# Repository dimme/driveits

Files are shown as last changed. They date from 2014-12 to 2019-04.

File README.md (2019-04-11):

# Drive ITS

This is the source code and schematics for the system described in the following papers:

* D. Vlastaras, T. Abbas, D. Leston, F. Tufvesson:
Vehicle Detection through Wireless Vehicular Communication, EURASIP Journal on Wireless Communications and Networking, 2014 2014:146.
* D. Vlastaras, T. Abbas, D. Leston, F. Tufvesson:
Universal Medium Range Radar and IEEE 802.11p Modem Solution for Integrated Traffic Safety, 13th International Conference on ITS Telecommunications, Tampere, Finland, pp. 193-197, 2013-11-05.
* D. Vlastaras, D. Leston:
Improved Traffic Safety by Wireless Vehicular Communication, Lund University, Sweden, 2013-06-17.

Everything is released under the GPLv3 license. For any commercial purposes please contact dimitrios@NOSPAM@cryodev.se

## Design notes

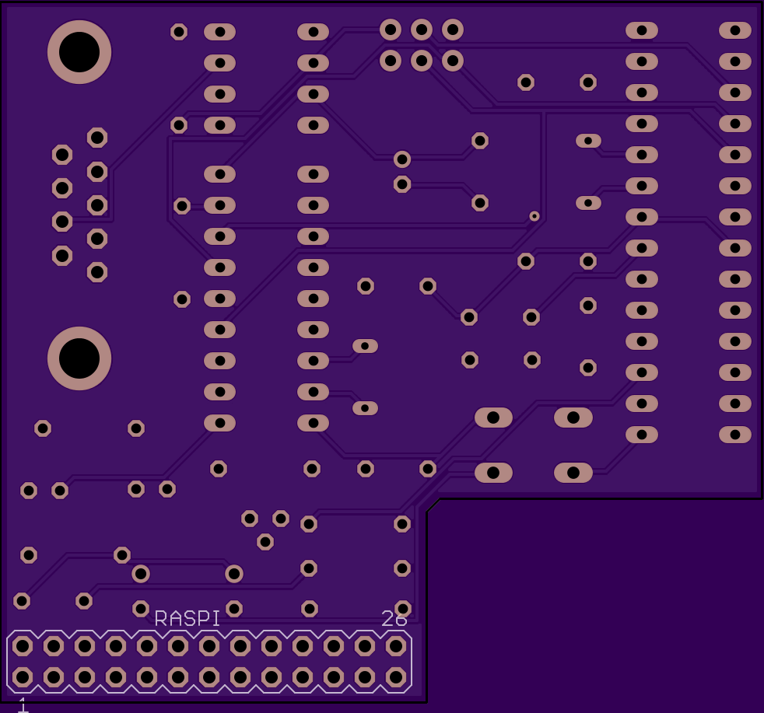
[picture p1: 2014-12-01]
hardware/pictures/bottom oshpark.png

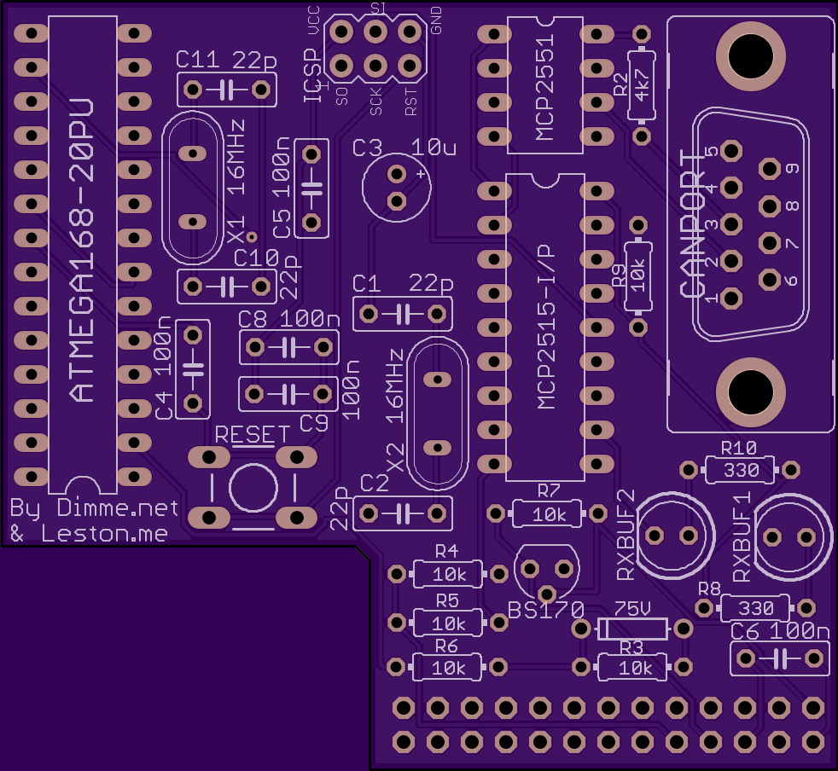
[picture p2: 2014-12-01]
hardware/pictures/top oshpark.png

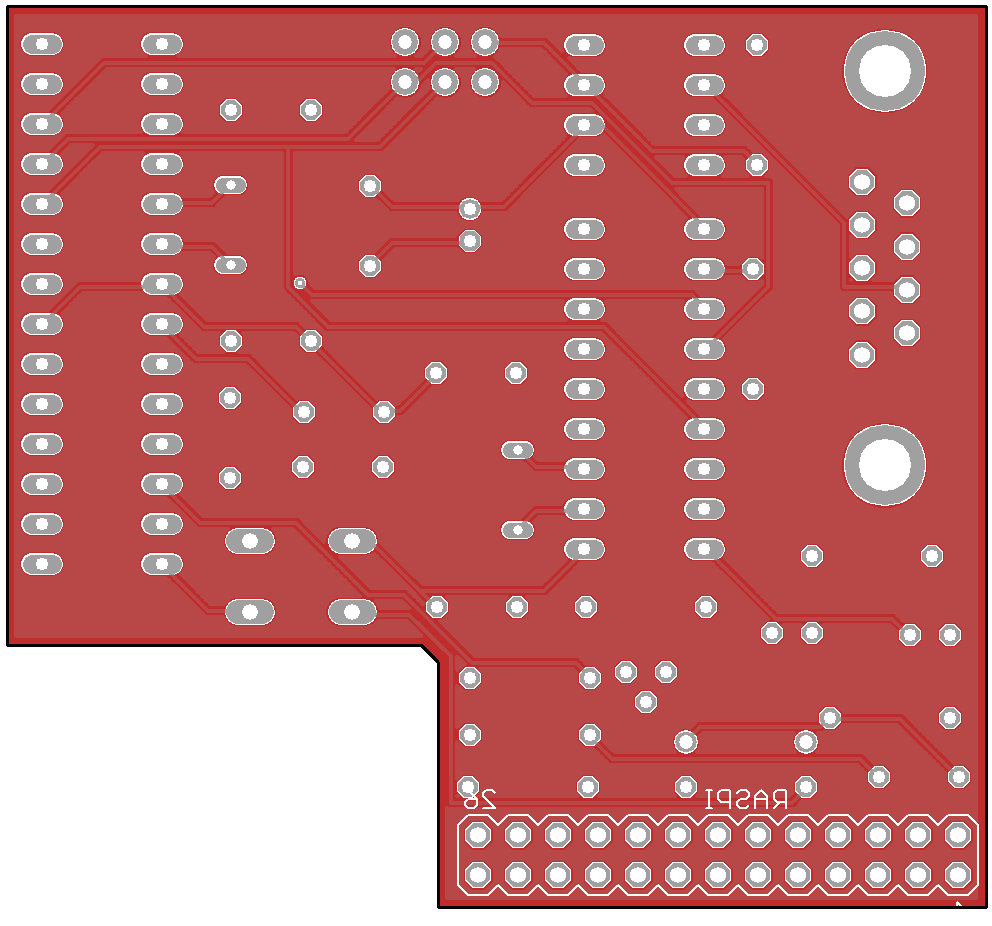
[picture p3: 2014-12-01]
hardware/pictures/bottom dirtypcbs.png

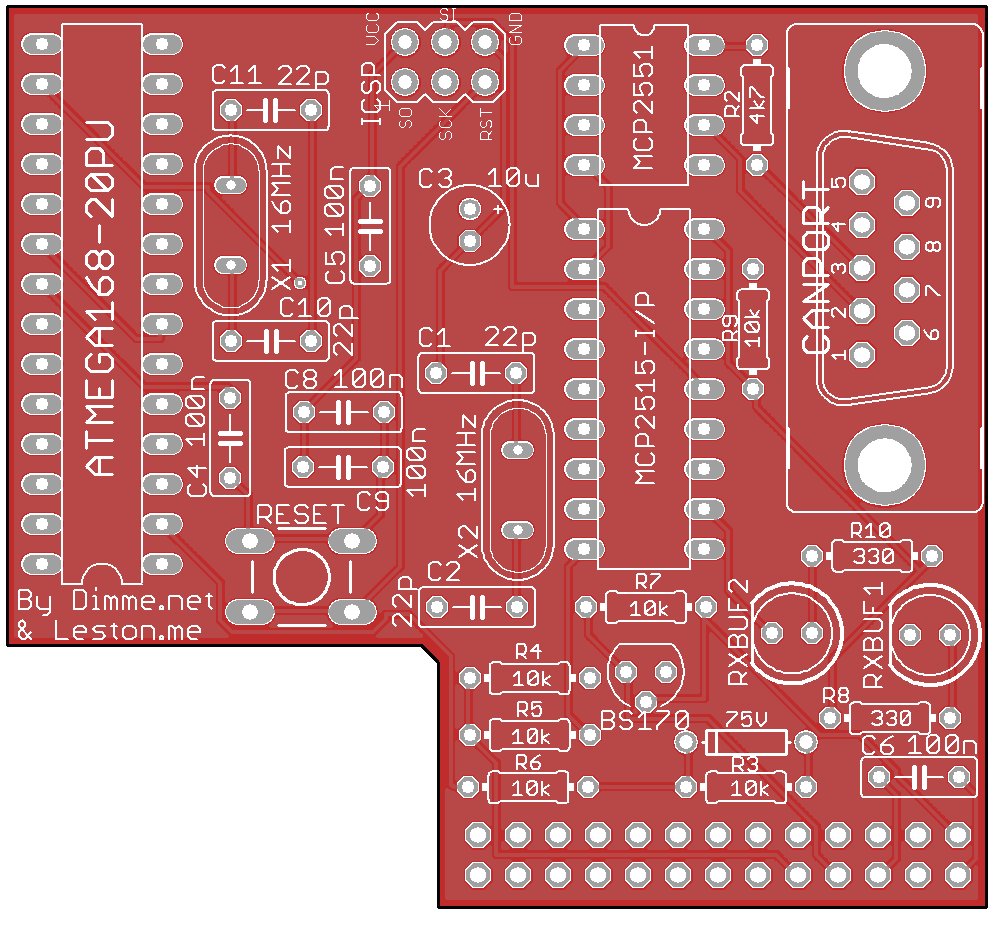
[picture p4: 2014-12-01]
hardware/pictures/top dirtypcbs.png

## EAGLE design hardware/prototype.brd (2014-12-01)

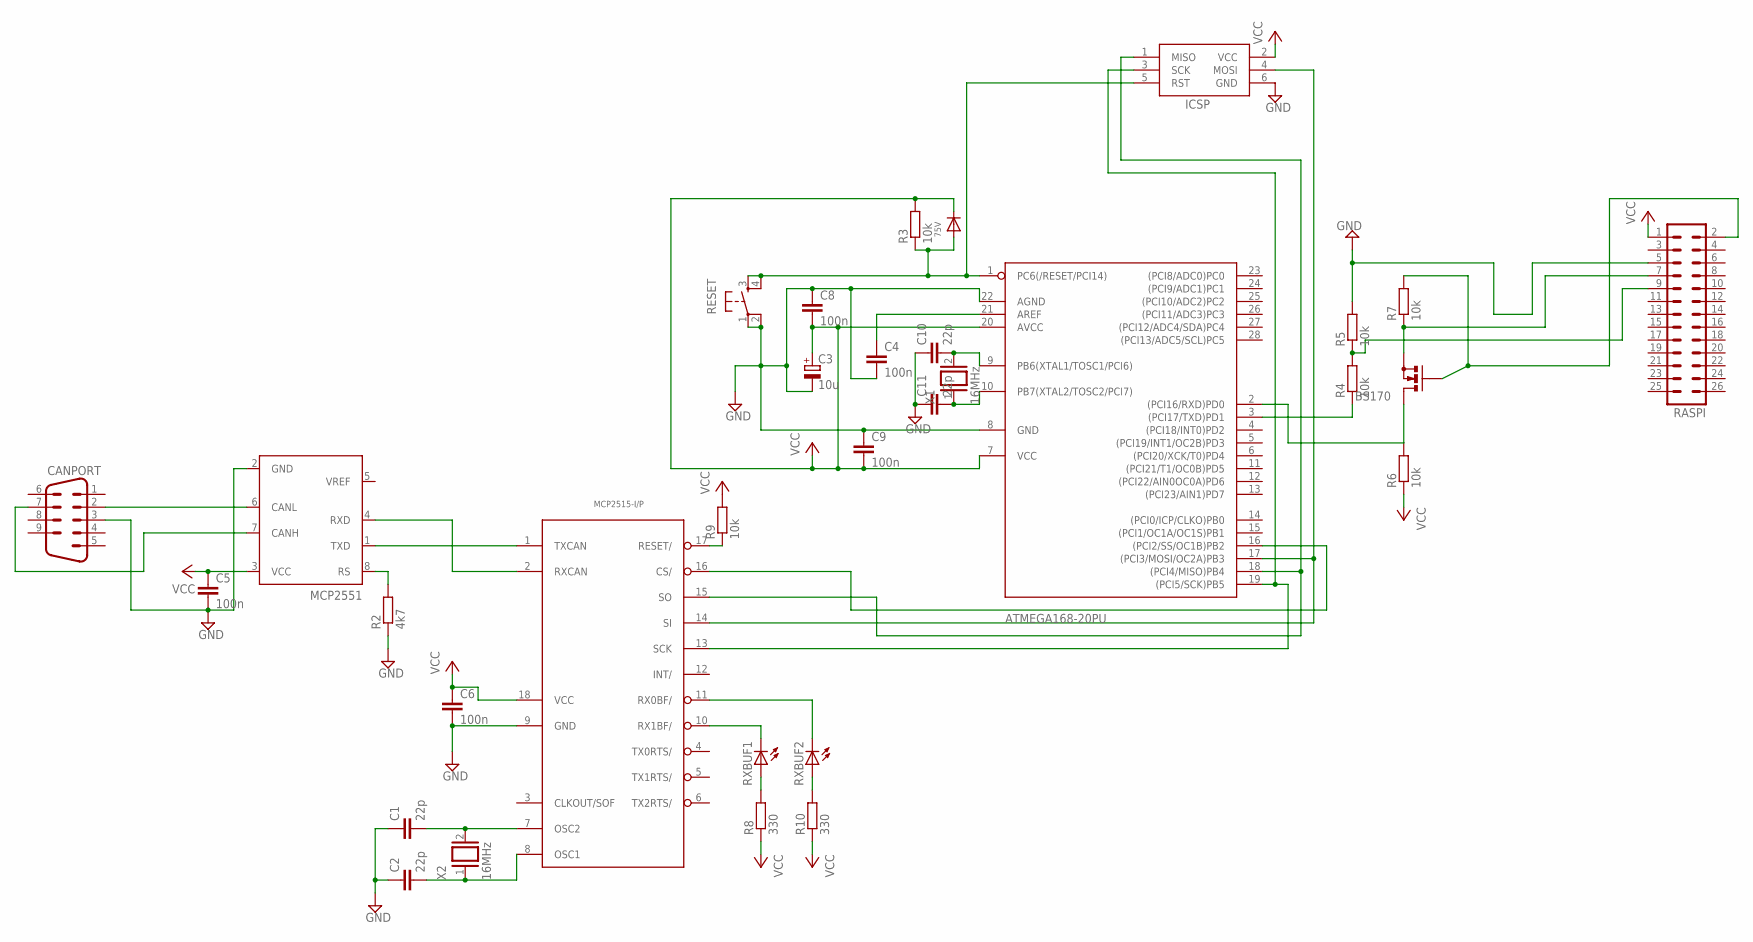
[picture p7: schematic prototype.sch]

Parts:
75V: DIODEDO-1N4148; DO-1N4148
ATMEGA168-20PU: ATMEGA168V-10P; DIL28-3
BS170: BS170; SOT54E
C1, C2, C10, C11: 22p; C050-025X075
C3: 10u; E2-5
C4, C5, C6, C8, C9: 100n; C050-025X075
CANPORT: M09VP
ICSP: AVRISP-6; AVRISP
MCP2515-I/P: MCP2515DIL; DIL18
MCP2551: PCA82C250; DIL08
R2: 4k7; 0204/7
R3, R4, R5, R6, R7, R9: 10k; 0204/7
R8, R10: 330; 0204/7
RASPI: MA13-2
RESET: DTS-6
RXBUF1, RXBUF2: LED5MM
X1, X2: 16MHz; QS

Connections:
GND: ATMEGA168-20PU.8 (GND), ATMEGA168-20PU.22 (AGND), C1.1, C2.1, C3.-, C4.2, C5.2, C6.2, C8.1, C9.1, C10.1, C11.1, CANPORT.3, ICSP.6 (GND), MCP2515-I/P.9 (GND), MCP2551.2 (GND), R2.1, R5.2, RASPI.5, RESET.1, RESET.2
unnamed: MCP2515-I/P.1 (TXCAN), MCP2551.1 (TXD)
unnamed: MCP2515-I/P.2 (RXCAN), MCP2551.4 (RXD)
unnamed: C1.2, MCP2515-I/P.7 (OSC2), X2.2
unnamed: C2.2, MCP2515-I/P.8 (OSC1), X2.1
unnamed: MCP2515-I/P.17 (RESET/), R9.1
unnamed: R8.2, RXBUF1.A
unnamed: R10.2, RXBUF2.A
unnamed: MCP2515-I/P.11 (RX0BF/), RXBUF2.K (C)
unnamed: MCP2515-I/P.10 (RX1BF/), RXBUF1.K (C)
unnamed: ATMEGA168-20PU.16 ((PCI2/SS/OC1B)PB2), MCP2515-I/P.16 (CS/)
unnamed: ATMEGA168-20PU.3 ((PCI17/TXD)PD1), R4.1
unnamed: ATMEGA168-20PU.19 ((PCI5/SCK)PB5), ICSP.3 (SCK), MCP2515-I/P.13 (SCK)
unnamed: ATMEGA168-20PU.9 (PB6(XTAL1/TOSC1/PCI6)), C10.2, X1.2
unnamed: ATMEGA168-20PU.10 (PB7(XTAL2/TOSC2/PCI7)), C11.2, X1.1
unnamed: MCP2551.8 (RS), R2.2
unnamed: ATMEGA168-20PU.21 (AREF), C4.1
unnamed: R4.2, R5.1, RASPI.9
unnamed: ATMEGA168-20PU.2 ((PCI16/RXD)PD0), BS170.D, R6.2
unnamed: 75V.A, ATMEGA168-20PU.1 (PC6(/RESET/PCI14)), ICSP.5 (RST), R3.1, RESET.3, RESET.4
unnamed: BS170.G, R7.2, RASPI.2
unnamed: ATMEGA168-20PU.18 ((PCI4/MISO)PB4), ICSP.1 (MISO), MCP2515-I/P.15 (SO)
unnamed: ATMEGA168-20PU.17 ((PCI3/MOSI/OC2A)PB3), ICSP.4 (MOSI), MCP2515-I/P.14 (SI)
unnamed: CANPORT.2, MCP2551.6 (CANL)
unnamed: CANPORT.7, MCP2551.7 (CANH)
unnamed: BS170.S, R7.1, RASPI.7
VCC: 75V.C, ATMEGA168-20PU.7 (VCC), ATMEGA168-20PU.20 (AVCC), C3.+, C5.1, C6.1, C8.2, C9.2, ICSP.2 (VCC), MCP2515-I/P.18 (VCC), MCP2551.3 (VCC), R3.2, R6.1, R8.1, R9.2, R10.1, RASPI.1

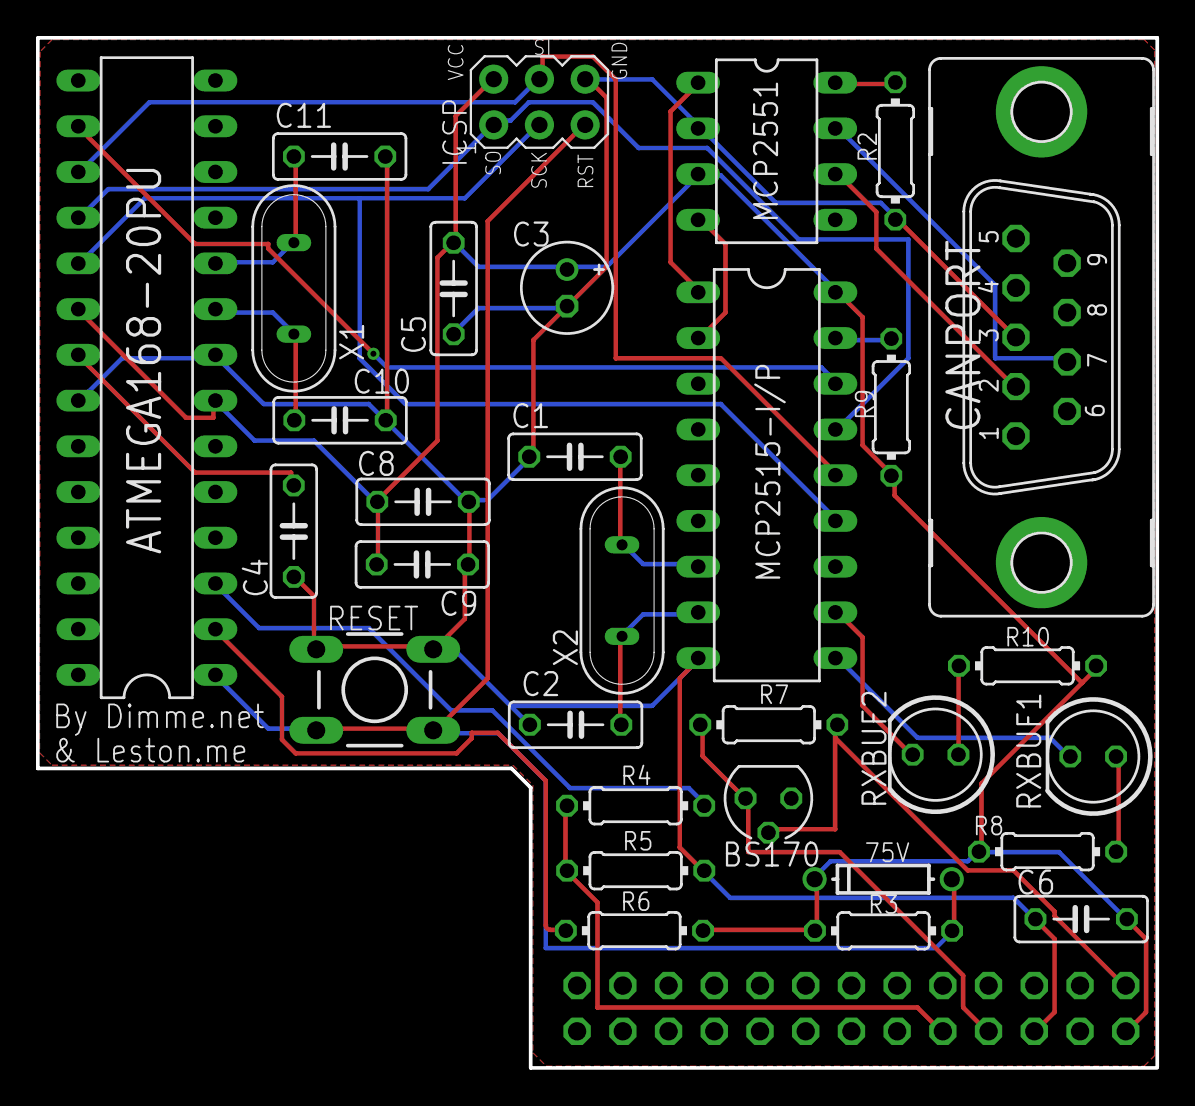
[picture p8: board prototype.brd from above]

Board: 2 copper layers, 62.2 x 57.2 mm, 32 parts (1 on the bottom side), 27 nets.

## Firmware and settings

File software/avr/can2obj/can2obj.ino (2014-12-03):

#include <SoftwareSerial.h>
#include <SPI.h>
#include "CAN.h"

// Read the report for the reason why we selected this baudrate
#define RS232_BAUD 57600

// Other defines
#define FRAME_LENGTH_WITHOUT_CRC 21

// Global variables
bool wakeUpCall = 1, sendRequest = 1, simulated = 0, valsReceived = 0;
byte rxStatus, length, frameData[8], extended, filter, startingFlag[] = { 
  0xFF,0xFF,0xFF,0xFF }, installationHeight = 5;
uint32_t frameID, oldTime = 0;

// Initiate everything
void setup() {
  // Use the defined serial port speed
  Serial.begin(RS232_BAUD);

  // Initialize CAN bus class
  // This class initializes SPI communications with MCP2515
  CAN.begin();
  delay(10);
  CAN.baudConfig();
  delay(10);

  CAN.resetFiltersAndMasks();
  CAN.toggleRxBuffer0Acceptance(true, false);
  CAN.toggleRxBuffer1Acceptance(true, false);
  CAN.setMode(NORMAL); // We send ACK's to every message that it is received.
}

// Send command for normal or simulated objects
void requestObjects(){
  byte data[] = { 0xFF,0x00,0x00,0x00,0x00,0x00,0x00,0x00 };
  if (simulated) data[4] = 0x08;
  sendCommand(data);
}

// Send the command that set the installation height in meters
// Accepted values: 1...10 meters
void setInstallationHeight() {
  byte data[] = { 0xFF,0x01,0x00,0xAC,installationHeight,0x00,0x00,0x00 };
  sendCommand(data);
}

// Function for send a command to the radar
void sendCommand(byte data[]) {
  uint32_t frame_id = 0x3F2;
  byte length = 8;
  CAN.load_ff_0(length, &frame_id, data, false);
}

// Checks if a second has passed
//void checkIfSecondPassed() {
//  uint32_t time = millis();
//  if (time > oldTime + 1000) {
//    framesSentThisSecond = 0;
//    oldTime = time;
//  }
//}

// Checksum calculation for the frame
char checksum(const char * str) {
  uint8_t sum = 0;
  for (uint8_t i = 0; i < FRAME_LENGTH_WITHOUT_CRC; i++) {
    sum += (uint8_t)str[i];
  }
  return 'H' + sum % 16;
}

// Runtime loop
void loop() {
  // Check if it's time to perform the action
  //checkIfSecondPassed();

  if (valsReceived) {
    // First we send a frame in order to wake up the sensor
    if (wakeUpCall) {
      requestObjects();
      wakeUpCall = 0;  
    }
  
    // Read the status of the RX buffers
    rxStatus = CAN.readStatus();
  
    // Depending on the RX status, read the correct buffer
    bool buffer0 = CAN.buffer0DataWaiting();
    bool buffer1 = CAN.buffer1DataWaiting();
    if (buffer0) {
      CAN.readDATA_ff_0(&length,frameData,&frameID, &extended, &filter);
    } 
    else if (buffer1) {
      CAN.readDATA_ff_1(&length,frameData,&frameID, &extended, &filter);
    }
  
    // Now that we have read the correct buffer, filter the data and send it through serial
    if (buffer0 || buffer1) {
  
      // Once sensor booted, send the request to the sensor to start detecting normal or simulated traffic 
      if(sendRequest && frameID == 0x2FF){
        requestObjects();
        setInstallationHeight();
        sendRequest = 0;
      }
  
      //if (frameID == 0x2FF) {
      //Serial.print("New cycle!\n"); 
      //}
  
      // Moving object detected
      if ((frameID >= 0x510 && frameID <= 0x54F) ||
        (frameID >= 0x590 && frameID <= 0x5CF) ||
        (frameID >= 0x610 && frameID <= 0x64F) ||
        (frameID >= 0x690 && frameID <= 0x6CF))
      {
  
        // Generate and send serial frame with header and checksum
        byte objectID = frameData[7] >> 2;
        byte objectLength = frameData[7] << 14 >> 8 | frameData[6] >> 2;
        int16_t yVelocity = frameData[6] << 14 >> 5 | frameData[5] << 1 | frameData[4] >> 7;
        int16_t xVelocity = frameData[4] << 9 >> 5 | frameData[3] >> 4;
        yVelocity = yVelocity < 0 ? -(1024 + yVelocity) : 1024 - yVelocity;
        xVelocity = xVelocity < 0 ? -(1024 + xVelocity) : 1024 - xVelocity;
        int16_t yPosition = (frameData[3] << 12 >> 2 | frameData[2] << 2 | frameData[1] >> 6) + 8192;
        int16_t xPosition = (frameData[1] << 10 >> 2 | frameData[0]) + 8192;
  
        char frame[FRAME_LENGTH_WITHOUT_CRC];
        sprintf(frame,"G%02X%02X%04X%04X%04X%04X",objectID,objectLength,xPosition,yPosition,xVelocity,yVelocity);
        Serial.print(frame);
        Serial.print(checksum(frame));
      }
    }    
  } else {
    
    // Read the operation mode and installation height byte
    if (Serial.available() > 0) {
      // Read the init byte:
      byte initByte = Serial.read();
      
      simulated = (bool) (initByte >> 4);
      installationHeight = (byte) (((byte)(initByte << 4)) >> 4);
  
      // What we got:
      //Serial.println("I received: ");
      //Serial.println(simulated, DEC);
      //Serial.println(installationHeight, DEC);
      valsReceived = 1;
    }
  }
}

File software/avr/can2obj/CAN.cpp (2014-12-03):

#include <SPI.h>
#include <SoftwareSerial.h>
#include "CAN.h"

void CANClass::begin()//constructor for initializing can module.
{
  // set the slaveSelectPin as an output 
  pinMode (SCK_PIN,OUTPUT);
  pinMode (MISO_PIN,INPUT);
  pinMode (MOSI_PIN, OUTPUT);
  pinMode (SS_PIN, OUTPUT);
  pinMode(RESET_PIN,OUTPUT);
  pinMode(INT_PIN,INPUT);
  digitalWrite(INT_PIN,HIGH);

  // initialize SPI:
  SPI.begin();
  SPI.setDataMode(SPI_MODE0);
  SPI.setClockDivider(SPI_CLOCK_DIV4);
  SPI.setBitOrder(MSBFIRST);

  digitalWrite(RESET_PIN,LOW); /* RESET CAN CONTROLLER*/
  delay(10);
  digitalWrite(RESET_PIN,HIGH);
  delay(100);

  resetFiltersAndMasks();
}

void CANClass::baudConfig()
{
  // Values for 250kbaud with 16MHz oscillator
  byte config0 = 0xC1,config1 = 0xB8,config2 = 0x05; //

  // Put it in configuration mode
  setMode(CONFIGURATION);
  delay(10);

  // Set the registers
  setRegister(CNF0,config0);
  setRegister(CNF1,config1);
  setRegister(CNF2,config2);

  // Set output LEDs
  // See data sheet for explanation
  digitalWrite(SS_PIN,LOW);
  delay(10);
  SPI.transfer(BIT_MODIFY);
  SPI.transfer(BFPCTRL);
  SPI.transfer(0b1111);
  SPI.transfer(0b1111);
  delay(10);
  digitalWrite(SS_PIN,HIGH);
  delay(10);
}

void CANClass::setMaskOrFilter(byte mask, byte b0, byte b1, byte b2, byte b3) {
  setMode(CONFIGURATION);  
  setRegister(mask, b0);
  setRegister(mask+1, b1);
  setRegister(mask+2, b2);
  setRegister(mask+3, b3);
  setMode(NORMAL);
}

void CANClass::setRegister(byte reg, byte value) {
  digitalWrite(SS_PIN, LOW);
  delay(10);
  SPI.transfer(WRITE);
  SPI.transfer(reg);
  SPI.transfer(value);
  delay(10);
  digitalWrite(SS_PIN, HIGH);
  delay(10);
}

// Method added to enable testing in loopback mode.(pcruce_at_igpp.ucla.edu)
void CANClass::setMode(CANMode mode) { //put CAN controller in one of five modes

  byte writeVal = 0x00,mask = 0xE0;

  switch(mode) {
  case CONFIGURATION:
    writeVal = 0x80;
    break;
  case NORMAL:
    writeVal = 0x00;
    break;
  case SLEEP:
    writeVal = 0x20;
    break;
  case LISTEN:
    writeVal = 0x60;
    break;
  case LOOPBACK:
    writeVal = 0x40;
    break;
  }

  digitalWrite(SS_PIN, LOW);
  SPI.transfer(BIT_MODIFY);
  SPI.transfer(CANCTRL);
  SPI.transfer(mask);
  SPI.transfer(writeVal);
  digitalWrite(SS_PIN, HIGH);

}

//extending CAN data read to full frames(pcruce_at_igpp.ucla.edu)
//It is the responsibility of the user to allocate memory for output.
//If you don't know what length the bus frames will be, data_out should be 8-bytes
void CANClass::readDATA_ff_0(byte* length_out, byte *data_out, uint32_t *id_out, byte *ext, byte *filter){
  readRXBuffer(READ_RX_BUF_0_ID, length_out, data_out, id_out, ext, filter);
}

void CANClass::readDATA_ff_1(byte* length_out, byte *data_out, uint32_t *id_out, byte *ext, byte *filter){
  readRXBuffer(READ_RX_BUF_1_ID, length_out, data_out, id_out, ext, filter);
}

void CANClass::readRXBuffer(byte buffer, byte* length_out, byte *data_out, uint32_t *id_out, byte *ext, byte *filter) {
  byte id_h,id_l,len,i,ed_8,ed_0;

  digitalWrite(SS_PIN, LOW);
  SPI.transfer(buffer);
  id_h = (unsigned short) SPI.transfer(0xFF); //id high
  id_l = (unsigned short) SPI.transfer(0xFF); //id low
  ed_8 = (unsigned short) SPI.transfer(0xFF); //extended id high(unused)
  ed_0 = (unsigned short) SPI.transfer(0xFF); //extended id low(unused)
  len = (SPI.transfer(0xFF) & 0x0F); //data length code
  for (i = 0;i<len;i++) {
    data_out[i] = SPI.transfer(0xFF);
  }
  digitalWrite(SS_PIN, HIGH);

  (*length_out) = len;
  if ((id_l & 0x08) == 0x08)  {
    *((uint16_t *) id_out + 1)  = (uint16_t) id_h << 5;
    *((uint8_t *)  id_out + 1)  = ed_8;
    *((uint8_t *)  id_out + 2) |= (id_l >> 3) & 0x1C;
    *((uint8_t *)  id_out + 2) |=  id_l & 0x03;
    *((uint8_t *)  id_out)      = ed_0;
    (*ext) = 1;
    //(*id_out) = (id_h << 21);// + ((id_l & 0xe0) << 13) + ((id_l & 0x03) << 16) + (ed_8 << 8) + ed_0;
  } 
  else {
    (*id_out) = ((id_h << 3) + ((id_l & 0xE0) >> 5)); //repack identifier
    (*ext) = 0;
  }
  (*filter) = getFilterHit(buffer);
}

//Adding method to read status register
//can be used to determine whether a frame was received.
//(readStatus() & 0x80) == 0x80 means frame in buffer 0
//(readStatus() & 0x40) == 0x40 means frame in buffer 1
byte CANClass::readStatus() 
{
  byte retVal;
  digitalWrite(SS_PIN, LOW);
  SPI.transfer(RX_STATUS);
  retVal = SPI.transfer(0xFF);
  SPI.transfer(0xFF);
  digitalWrite(SS_PIN, HIGH);
  return retVal;
}

void CANClass::load_ff(byte txbuf, byte length, uint32_t *id, byte *data, bool ext, byte send_cmd)
{
  digitalWrite(SS_PIN, LOW);
  SPI.transfer(txbuf);
  if (ext) {
    SPI.transfer(*((uint16_t *) id + 1) >> 5);
    //uint8_t tmp  = ;
    SPI.transfer(((*((uint8_t *) id + 2) << 3) & 0xe0) | (1 << 3) | ((*((uint8_t *) id + 2)) & 0x03));
    SPI.transfer(*((uint8_t *) id + 1));
    SPI.transfer(*((uint8_t *) id));
  } 
  else {
    SPI.transfer((byte) (*id >> 3)); //identifier high bits
    SPI.transfer((byte) ((*id << 5) & 0x00E0)); //identifier low bits
    SPI.transfer(0x00); //extended identifier registers(unused)
    SPI.transfer(0x00);
  }
  SPI.transfer(length);
  for (byte i=0;i<length;i++) { //load data buffer
    SPI.transfer(data[i]);
  }
  digitalWrite(SS_PIN, HIGH);
  delay(50);
  digitalWrite(SS_PIN, LOW);
  SPI.transfer(send_cmd);
  digitalWrite(SS_PIN, HIGH);
}

void CANClass::load_ff_0(byte length, uint32_t *id, byte *data, bool ext) {
  load_ff(LOAD_TX_BUF_0_ID, length, id, data, ext, SEND_TX_BUF_0);
}

void CANClass::load_ff_1(byte length, uint32_t *id, byte *data, bool ext)
{
  load_ff(LOAD_TX_BUF_1_ID, length, id, data, ext, SEND_TX_BUF_1);
}

void CANClass::load_ff_2(byte length, uint32_t *id, byte *data, bool ext)
{
  load_ff(LOAD_TX_BUF_2_ID, length, id, data, ext, SEND_TX_BUF_2);
}

byte CANClass::getFilterHit(byte rxbuf) {
  byte retVal = 0;
  switch (rxbuf) { 
  case READ_RX_BUF_0_ID:
    digitalWrite(SS_PIN, LOW);
    SPI.transfer(READ);
    SPI.transfer(RXB0CTRL);
    retVal = SPI.transfer(0xff);
    digitalWrite(SS_PIN, HIGH);
    break;
  case READ_RX_BUF_1_ID:
    digitalWrite(SS_PIN, LOW);
    SPI.transfer(READ);
    SPI.transfer(RXB1CTRL);
    retVal = SPI.transfer(0xff);
    digitalWrite(SS_PIN, HIGH);
    break;
  }
  return retVal & 0x03;
}
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

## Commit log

2014-12-01 Version of the hardware as found on the thesis
    [prototype.brd, prototype.sch]
2014-12-01 Smaller PCB, also the placement of the RASPI port has been corrected and the Serial port error
    [prototype.job.brd, prototype.sch]
2014-12-01 Added gerbers for DirtyPCBs and OSHpark.
    [prototype.brd, prototype.job.brd, prototype.sch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]
